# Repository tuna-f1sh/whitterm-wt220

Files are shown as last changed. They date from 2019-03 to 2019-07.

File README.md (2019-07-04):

```bash
        __        _______    ____  ____   ___
        \ \      / /_   _|  |___ \|___ \ / _ \
         \ \ /\ / /  | |_____ __) | __) | | | |
          \ V  V /   | |_____/ __/ / __/| |_| |
           \_/\_/    |_|    |_____|_____|\___/
       --- JBR Engineering Research Ltd 2019 ---
```

Design files, firmware and linux scripts for my _clever_ serial terminal, the
Whitterm-220 - WT-220. 

The WT-220 is a homage to the VT-220, providing a physical RS232 terminal with
the full features of a Linux computer running on a Raspberry Pi.

## Raspberry Pi Hat (./whitterm-hat)

KiCad design files for the rear io-panel:

* USB-C input for USB-PD high current (3 A) supply to RPi. LEDs indicate
  detected current profile from UFP. I2C lines made available to SAMD for
  playing with USB-C device modes.
* MAX3232 RS232 transceiver provides RS232 level interface to RPi UART and SAMD
  UART.
* SAMD21 microcontroller provides boot button control of RPi over I2C and
  buffered IO. Can be programmed over USB-C CDC-serial device or ISP.
* Control of RPi power supply from SAMD. Off by default allows safe start up, only when power input suitable/ready.
* DIP switch control of device UART connections (SAMD, RPi, RS232).
* Board replaces laser cut acrylic back piece from original design - it is
  both electronically and mechanically integrated.
* Lots of status LEDs 😃.

**There where a few green wires required for the first production (1.0). I
rolled these changes into the schematic but not fully updated the PCB.**

## Firmware (./firmware)

Arduino compatible firmware for rear panel SAMD21. Acts as I2C slave and
controls supply to RPi via 'Boot' button:

### Simplified State Diagram

```mermaid
graph TB;
    OFF-->|boot pressed 500 ms|ON;
    ON-->|I2C booted cmd recieved|BOOTED;
    ON-->|I2C recieve booted timeout 20000 ms|I2C_TIMEOUT;
    BOOTED-->|I2C recieve booted timeout 20000 ms|I2C_TIMEOUT;
    BOOTED-->|boot pressed 3000 ms|SHUTDOWN_REQUESTED;
    I2C_TIMEOUT-->|boot pressed 3000 ms|SHUTDOWN;
    I2C_TIMEOUT-->|I2C booted cmd recieved|BOOTED;
    SHUTDOWN_REQUESTED-->|I2C shutdown cmd|SHUTDOWN;
    SHUTDOWN_REQUESTED-->|boot pressed|ON;
    SHUTDOWN-->OFF;
```

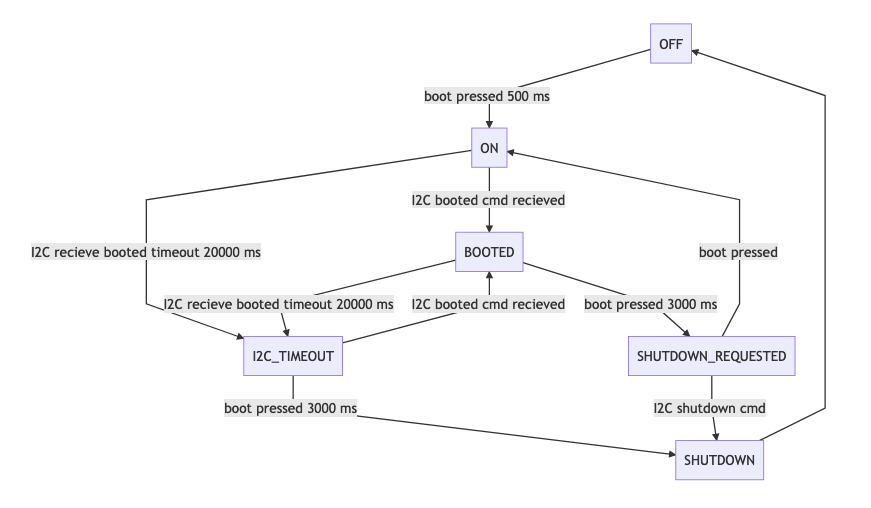
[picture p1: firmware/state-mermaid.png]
mermaid state


## RPi Files (./rpi)

I started from a base Raspbian Lite image rather than Arch for this build.
Raspbian Lite is nice because I could install only what I wanted/needed. I
opted for I3WM since it's a keyboard terminal.

### Services

* boot: Runs shell script that displays boot ascii logo.
* i2c: Runs python I2C script (wt220-i2c.py) that configures case LEDs to act
  on RX/TX and then maintains link with I2C link with SAMD. Polls shutdown
  request state and acts on request by issuing system shutdown.
* poweroff: Runs on 'shutdown.target' and issues the final I2C shutdown
  command so that SAMD disables RPi 5 V.

### Config Files

Would make an install script for this if I was making more...

* xinitrc -> /etc/X11/xinit/xinitrc
* config.txt, cmdline.txt -> /boot/
* Xresources -> ~/.Xresources
* motd -> /etc/motd
* wt220-sshbanner.net -> /etc/wt220-sshbanner.net `Banner /etc/wt220-sshbanner.net` in
  /etc/ssh/sshd_config
* \*services. -> /lib/systemd/system/
* scripts -> /opt/wt220/

### Packages

Need to manually install
[`cool-retro-term`](https://github.com/Swordfish90/cool-retro-term)

Other packages in 'rpi/dpkg-selections.txt'

## Breakout (./whitterm-breakout)

DB9 GPIO breakout from V 1.0 rear panel

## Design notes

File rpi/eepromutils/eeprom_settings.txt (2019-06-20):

########################################################################
# EEPROM settings text file
#
# Edit this file for your particular board and run through eepmake tool,
# then use eepflash tool to write to attached HAT ID EEPROM 
#
# Tools available:
#  eepmake   Parses EEPROM text file and creates binary .eep file
#  eepdump   Dumps a binary .eep file as human readable text (for debug)
#  eepflash  Write or read .eep binary image to/from HAT EEPROM
#
########################################################################

########################################################################
# Vendor info

# 128 bit UUID. If left at zero eepmake tool will auto-generate
# RFC 4122 compliant UUID
product_uuid 00000000-0000-0000-0000-000000000000

# 16 bit product id
product_id 0x0001

# 16 bit product version
product_ver 0x0001

# ASCII vendor string  (max 255 characters)
vendor "JBR Engineering Research Ltd"

# ASCII product string (max 255 characters)
product "WT-220 Rear IO-Panel"

########################################################################
# GPIO bank settings, set to nonzero to change from the default.
# NOTE these setting can only be set per BANK, uncommenting any of
# these will force the bank to use the custom setting.

# drive strength, 0=default, 1-8=2,4,6,8,10,12,14,16mA, 9-15=reserved
gpio_drive 0

# 0=default, 1=slew rate limiting, 2=no slew limiting, 3=reserved
gpio_slew 0

# 0=default, 1=hysteresis disabled, 2=hysteresis enabled, 3=reserved
gpio_hysteresis 0

# If board back-powers Pi via 5V GPIO header pins:
# 0 = board does not back-power
# 1 = board back-powers and can supply the Pi with a minimum of 1.3A
# 2 = board back-powers and can supply the Pi with a minimum of 2A
# 3 = reserved
# If back_power=2 then USB high current mode will be automatically 
# enabled on the Pi
back_power 2

########################################################################
# GPIO pins, uncomment for GPIOs used on board
# Options for FUNCTION: INPUT, OUTPUT, ALT0-ALT5
# Options for PULL: DEFAULT, UP, DOWN, NONE
# NB GPIO0 and GPIO1 are reserved for ID EEPROM so cannot be set

#         GPIO  FUNCTION  PULL
#         ----  --------  ----
#setgpio  2     INPUT     DEFAULT
#setgpio  3     INPUT     DEFAULT
#setgpio  4     INPUT     DEFAULT
#setgpio  5     INPUT     DEFAULT
#setgpio  6     INPUT     DEFAULT
#setgpio  7     INPUT     DEFAULT
#setgpio  8     INPUT     DEFAULT
#setgpio  9     INPUT     DEFAULT
#setgpio  10    INPUT     DEFAULT
#setgpio  11    INPUT     DEFAULT
#setgpio  12    INPUT     DEFAULT
#setgpio  13    INPUT     DEFAULT
#setgpio  14    INPUT     DEFAULT
#setgpio  15    INPUT     DEFAULT
#setgpio  16    INPUT     DEFAULT
#setgpio  17    INPUT     DEFAULT
#setgpio  18    INPUT     DEFAULT
#setgpio  19    INPUT     DEFAULT
#setgpio  20    INPUT     DEFAULT
#setgpio  21    INPUT     DEFAULT
#setgpio  22    INPUT     DEFAULT
#setgpio  23    INPUT     DEFAULT
#setgpio  24    INPUT     DEFAULT
#setgpio  25    INPUT     DEFAULT
#setgpio  26    INPUT     DEFAULT
#setgpio  27    OUTPUT    DEFAULT

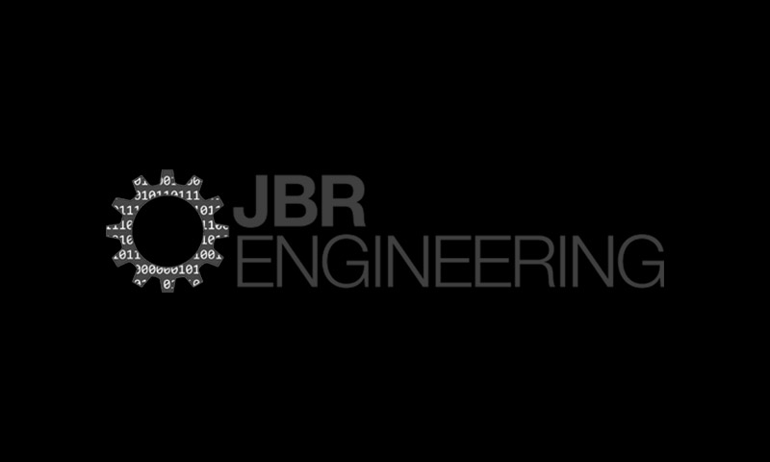
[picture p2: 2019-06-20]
rpi/wt220-background.jpg

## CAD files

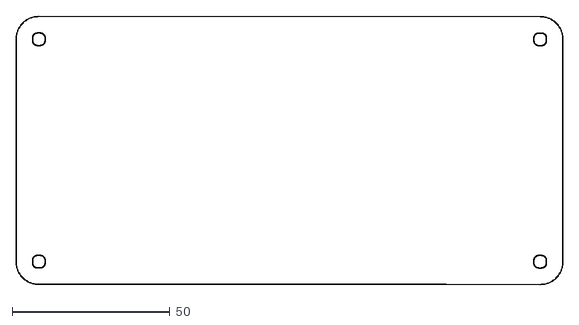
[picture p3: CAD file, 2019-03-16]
whitterm-hat/whitterm-rear-pcb.dxf
173.5 x 85.0

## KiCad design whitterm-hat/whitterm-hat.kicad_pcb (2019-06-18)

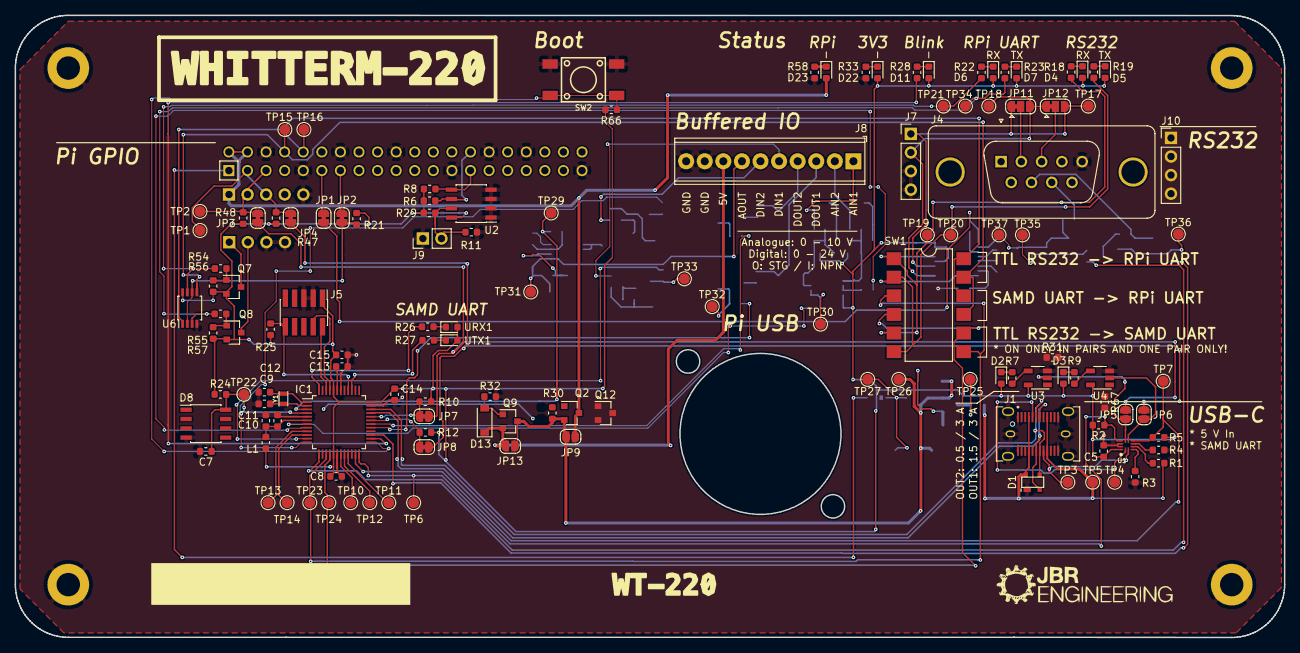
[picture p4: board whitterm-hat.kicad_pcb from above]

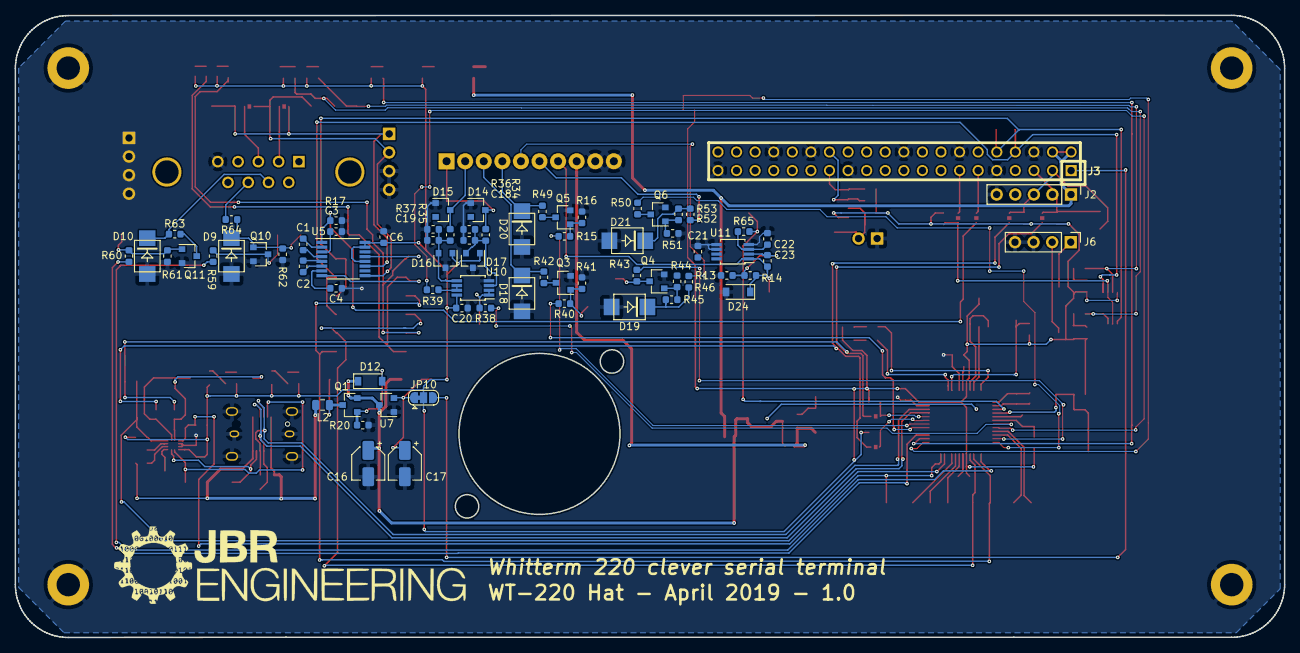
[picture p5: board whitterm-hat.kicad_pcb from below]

Board: 2 copper layers, 173.5 x 85.0 mm, 202 parts (72 on the bottom side), 127 nets.

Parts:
C1: 47nF; C_0603_1608Metric
C2, C3, C4: 330nF; C_0603_1608Metric
C5, C6, C18, C19, C20, C21: 100nF; C_0603_1608Metric
C7: 1uF; C_0603_1608Metric
C8, C10, C13, C14, C15: 0.1uF; C_0603_1608Metric
C9, C12: 15pF; C_0603_1608Metric
C11: 0.01uF; C_0603_1608Metric
C16, C17: 10uF; CP_Elec_4x5.3
C22: 470pF; C_0603_1608Metric
C23: 10pF; C_0603_1608Metric
D1: PRTR5V0U2X; SOT143B
D2: OUT2; LED_0603_1608Metric
D3: OUT1; LED_0603_1608Metric
D4: TLRX; LED_0603_1608Metric
D5: TLTX; LED_0603_1608Metric
D6: RXD; LED_0603_1608Metric
D7: TXD; LED_0603_1608Metric
D8: LM285D-2.5G; SOIC-8_3.9x4.9mm_P1.27mm
D9, D10, D18, D19, D20, D21: SMAJ30A-TR; D_DO-214AA
D11: D13; LED_0603_1608Metric
D12, D13: MMSZ16T1G; D_SOD-123
D14, D15: BZX84C10LT1G; D_SOT-23_ANK
D16, D17: BAV99; SOT-23
D22, D23: KP-2012MGC; LED_0603_1608Metric
D24: SMAJ12A-TR; D_SOD-123
IC1: SAMD21G18A; TQFP-48_7x7mm_P0.5mm
J1: USB_C_Receptacle; USB_C_Receptacle_JAE_DX07S024WJ1R350
J2: Touch I2C; PinHeader_1x05_P2.54mm_Vertical
J3: 40HAT; HEADER-2x20-REVERSE
J4: DB9_Male; DSUB-9_Male_Vertical_P2.77x2.84mm_MountingHoles
J5: Conn_02x05_Odd_Even; PinHeader_2x05_P1.27mm_Vertical_SMD
J6, J7, J10: Conn_01x04_Female; PinHeader_1x04_P2.54mm_Vertical
J8: Conn_01x10_Female; TerminalBlock_Phoenix_MPT-0,5-10-2.54_1x10_P2.54mm_Horizont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
J9: CONN_01X02; PinHeader_1x02_P2.54mm_Vertical
JP1, JP2, JP3, JP4, JP7, JP8: Jumper_2_Bridged; SolderJumper-2_P1.3mm_Bridged_RoundedPad1.0x1.5mm
JP5, JP6, JP9, JP13: Jumper_NO_Small; SolderJumper-2_P1.3mm_Open_RoundedPad1.0x1.5mm
JP10, JP11, JP12: SolderJumper_3_Bridged12; SolderJumper-3_P1.3mm_Bridged12_RoundedPad1.0x1.5mm
L1: LM18P; L_0603_1608Metric
L2: Ferrite_Bead_Small; L_0805_2012Metric
Q1, Q2, Q7, Q8, Q9: IRLML6402PBF; SOT-23
Q3, Q4, Q5, Q6, Q10, Q11, Q12: BC850; SOT-23
R1: 900k; R_0603_1608Metric
R2, R5, R17, R20, R21, R24, R25, R30, R31, R32, R56, R57, R66, R67: 10k; R_0603_1608Metric
R3, R4: 0R; R_0603_1608Metric
R6, R8, R10, R12, R47, R48: 4.7K; R_0603_1608Metric
R7, R9, R18, R19, R22, R23, R26, R27, R28, R33: 150R; R_0603_1608Metric
R11: DNP; R_0603_1608Metric
R13, R14: 100k; R_0603_1608Metric
R15, R40, R42, R43, R45, R46, R49, R50, R52, R53, R54, R55, R59, R60, R63, R64: 470R; R_0603_1608Metric
R16, R38, R39, R41, R44, R51, R61, R62, R65: 1k; R_0603_1608Metric
R29: 10K; R_0603_1608Metric
R34, R35: 9k1; R_0603_1608Metric
R36, R37: 3k9; R_0603_1608Metric
R58: 220R; R_0603_1608Metric
SW1: SW_DIP_x06; SMDIP-12_W9.53mm
SW2: SW_Push; SPST-4-PIN_6mm_sm
TP1, TP2, TP3, TP4, TP5, TP6, TP7, TP10, TP11, TP12, TP13, TP14, TP15, TP16, TP17, TP18, TP19, TP20, TP21, TP22, TP23, TP24, TP25, TP26, TP27, TP29, TP30, TP31, TP32, TP33, TP34, TP35, TP36, TP37: TestPoint; TestPoint_Pad_D1.5mm
U1: TUSB320; TI_RWB_X2QFN-12
U2: CAT24C32WI-GT3; SOIC-8_3.9x4.9mm_P1.27mm
U3, U4: 74LVC1G17; TSOT-23-5
U5: MAX3221; TSSOP-16_4.4x5mm_P0.65mm
U6: 74LVC2G02; TSSOP-8_3x3mm_P0.65mm
U7: MCP1703A-3302_SOT23; SOT-23
U10, U11: ADA4807-2ARM; MSOP-8_3x3mm_P0.65mm
URX1: RXD; LED_0603_1608Metric
UTX1: TXD; LED_0603_1608Metric
Y1: 32.768; Crystal_2-SMD_2x1.2mm
svg2mod: G***; whitterm220-fullname
svg2mod#2: G***; whitterm220-wt220

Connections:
+5V: C16.1, C21.2, D12.1, JP9.1, JP13.1, Q1.2, Q2.2, Q9.3, R30.1, TP26.1, U7.3, U11.8
/D+: D1.3, IC1.34, J1.A6, J1.B6
/D-: D1.2, IC1.33, J1.A7, J1.B7
/EXT_5VO: D13.1, J8.8, JP13.2, Q9.2
/ID_SC_EEPROM: J3.28, R6.1, U2.6
/ID_SD_EEPROM: J3.27, R8.1, U2.5
/PI_3V3: J3.1, JP10.3
/PI_5V: D23.2, J2.1, J3.2, J3.4, JP9.2, Q2.3
/PI_EN: IC1.14, Q12.1
/PI_RXD: J3.10, J10.1, SW1.10, SW1.12, TP16.1, U6.1
/PI_SCL: J2.2, J3.5, JP3.1, R48.1, TP2.1
/PI_SDA: J2.3, J3.3, JP4.1, R47.1, TP1.1
/PI_TXD: J3.8, J10.2, SW1.9, SW1.11, TP15.1, U6.5
/RS232-UART/RS232_CTS: J4.8, R64.2
/RS232-UART/RS232_RTS: D10.1, J4.7, R63.1
/RS232-UART/RS232_RX: J7.1, JP11.1, JP12.3, TP17.1, U5.11
/RS232-UART/RS232_TX: J7.2, JP11.3, JP12.1, TP18.1, U5.9
/RS232-UART/RXD_LEDC: J6.1, Q7.3
/RS232-UART/TTL_RX: R18.1, SW1.1, SW1.5, TP19.1, U5.13
/RS232-UART/TTL_TX: R19.1, SW1.2, SW1.6, TP20.1, U5.8
/RS232-UART/TXD_LEDC: J6.2, Q8.3
/SAMD_RXD: IC1.16, J10.3, SW1.4, SW1.8, TP24.1
/SAMD_TXD: IC1.15, J10.4, SW1.3, SW1.7, TP23.1
/USBC_ID: IC1.24, R2.1, TP6.1, U1.9
/USBC_INT: IC1.23, R5.1, TP7.1, U1.6
/USBC_SCL: JP3.2, JP5.2, JP7.1
/USBC_SDA: JP4.2, JP6.2, JP8.1
/U_CTS: IC1.13, R59.1
/U_RTS: IC1.27, R60.2
/buffers/AIN_I1: D14.1, J8.1, R34.2
/buffers/AIN_I2: D15.1, J8.2, R35.2
/buffers/AOUT_O1: C23.1, D24.1, J8.7, R14.1, TP31.1, U11.1
/buffers/DIN_I1: J8.5, R46.2
/buffers/DIN_I2: J8.6, R53.2
/buffers/DOUT_O1: D18.1, J8.3, R42.1
/buffers/DOUT_O2: D20.1, J8.4, R49.1
/microcontroller/A0_DAC: IC1.3, R65.2, TP29.1
/microcontroller/A1: IC1.7, R38.1
/microcontroller/A2: IC1.8, R39.1
/microcontroller/A3: IC1.9, TP13.1
/microcontroller/A4: IC1.10, TP14.1
/microcontroller/D6: IC1.29, R40.2
/microcontroller/D7: IC1.30, R15.2
/microcontroller/D8: IC1.11, R43.1
/microcontroller/D9: IC1.12, R50.1
/microcontroller/D11: IC1.25, R66.2, SW2.2
/microcontroller/D13: IC1.26, R28.1
/microcontroller/MISO: IC1.21, TP11.1
/microcontroller/MOSI: IC1.19, TP10.1
/microcontroller/NRST: IC1.40, J5.10, R25.2
/microcontroller/RX_LED: IC1.48, R26.1
/microcontroller/SCK: IC1.20, TP12.1
/microcontroller/SCL: IC1.32, JP7.2, R10.1
/microcontroller/SDA: IC1.31, JP8.2, R12.1
/microcontroller/SWDCLK: IC1.45, J5.4
/microcontroller/SWDIO: IC1.46, J5.2
/microcontroller/TX_LED: IC1.39, R27.1
/~RPI_EN_ACT: JP2.1, R21.1, U6.2, U6.6
/~RS232_EN: JP1.1, R17.2, U5.1
GND: C3.1, C4.1, C5.1, C6.1, C7.2, C8.2, C9.2, C10.2, C11.2, C12.2, C13.2, C14.2, C15.2, C16.2, C17.2, C18.2, C19.2, C20.1, C21.1, C22.2, D1.1, D8.4, D9.2, D10.2, D14.2, D15.2, D16.3, D17.3, D18.2, D19.2, D20.2, D21.2, D24.2, IC1.5, IC1.18, IC1.35, IC1.42, J1.A1, J1.A12, J1.B1, J1.B12, J1.S1, J2.5, J3.6, J3.9, J3.14, J3.20, J3.25, J3.30, J3.34, J3.39, J4.5, J5.3, J5.5, J6.3, J6.4, J7.3, J7.4, J8.9, J8.10, J9.1, Q3.2, Q4.2, Q5.2, Q6.2, Q10.2, Q11.2, Q12.2, R3.1, R4.1, R11.2, R13.1, R16.1, R17.1, R20.2, R32.2, R33.2, R36.1, R37.1, R41.1, R44.1, R51.1, R58.2, R61.1, R62.1, SW2.1, U1.10, U1.11, U2.1, U2.2, U2.3, U2.4, U3.3, U4.3, U5.14, U6.4, U7.1, U10.4, U11.4, U11.5, U11.6
unnamed: C1.1, U5.2
unnamed: C1.2, U5.4
unnamed: C2.1, U5.5
unnamed: C2.2, U5.6
unnamed: C3.2, U5.3
unnamed: C4.2, U5.7
unnamed: C7.1, D8.8, IC1.4, R24.2, TP22.1
unnamed: C9.1, IC1.2, Y1.1
unnamed: C10.1, C11.1, IC1.6, L1.1
unnamed: C12.1, IC1.1, Y1.2
unnamed: C13.1, IC1.43
unnamed: C17.1, JP10.1, TP27.1, U7.2
unnamed: C18.1, D17.2, R34.1, R36.2, U10.3
unnamed: C19.1, D16.2, R35.1, R37.2, U10.5
unnamed: C22.1, R65.1, U11.3
unnamed: C23.2, R13.2, R14.2, U11.2
unnamed: D2.1, R7.2
unnamed: D3.1, R9.2
unnamed: D4.1, R18.2
unnamed: D5.1, R19.2
unnamed: D6.1, R22.2
unnamed: D7.1, R23.1
unnamed: D9.1, Q10.1, R62.2, R64.1, TP37.1
unnamed: D11.1, R28.2
unnamed: D12.2, Q1.1, R20.1
unnamed: D13.2, Q9.1, R32.1
unnamed: D19.1, R45.2, R46.1
unnamed: D21.1, R52.2, R53.1
unnamed: D22.1, R33.1
unnamed: D23.1, R58.1
unnamed: J1.A5, TP4.1, U1.1
unnamed: J1.B5, TP3.1, U1.2
unnamed: J3.11, JP1.2
unnamed: J3.13, JP2.2
unnamed: J4.2, JP11.2
unnamed: J4.3, JP12.2
unnamed: J9.2, R11.1, R29.1, U2.7
unnamed: JP5.1, R31.1, U1.8, U3.2
unnamed: JP6.1, R67.1, U1.7, U4.2
unnamed: L2.1, Q1.3, TP25.1
unnamed: Q3.1, R40.1, R41.2, TP32.1
unnamed: Q3.3, R42.2
unnamed: Q4.1, R44.2, R45.1
unnamed: Q4.3, R43.2, TP33.1
unnamed: Q5.1, R15.1, R16.2
unnamed: Q5.3, R49.2
unnamed: Q6.1, R51.2, R52.1
unnamed: Q6.3, R50.2
unnamed: Q7.1, R54.2, R56.1
unnamed: Q8.1, R55.2, R57.1
unnamed: Q10.3, R59.2, TP35.1
unnamed: Q11.1, R60.1, R61.2, TP36.1
unnamed: Q11.3, R63.2
unnamed: Q2.1, Q12.3, R30.2
unnamed: R1.1, U1.4
unnamed: R3.2, U1.3
unnamed: R4.2, U1.5
unnamed: R7.1, U3.4
unnamed: R9.1, U4.4
unnamed: R22.1, R54.1, TP21.1, U6.7
unnamed: R23.2, R55.1, TP34.1, U6.3
unnamed: R26.2, URX1.1
unnamed: R27.2, UTX1.1
unnamed: R38.2, TP30.1, U10.1, U10.2
unnamed: R39.2, U10.6, U10.7
VBUS: D1.4, J1.A4, J1.A9, J1.B4, J1.B9, L2.2, R1.2, TP5.1
VCC: C5.2, C6.2, C8.1, C14.1, C15.1, C20.2, D2.2, D3.2, D4.2, D5.2, D6.2, D7.2, D11.2, D16.1, D17.1, D22.2, IC1.17, IC1.36, IC1.44, J5.1, JP10.2, L1.2, Q7.2, Q8.2, R2.2, R5.2, R6.2, R8.2, R10.2, R12.2, R21.2, R24.1, R25.1, R29.2, R31.2, R47.2, R48.2, R56.2, R57.2, R66.1, R67.2, U1.12, U2.8, U3.5, U4.5, U5.12, U5.15, U5.16, U6.8, U10.8, URX1.2, UTX1.2

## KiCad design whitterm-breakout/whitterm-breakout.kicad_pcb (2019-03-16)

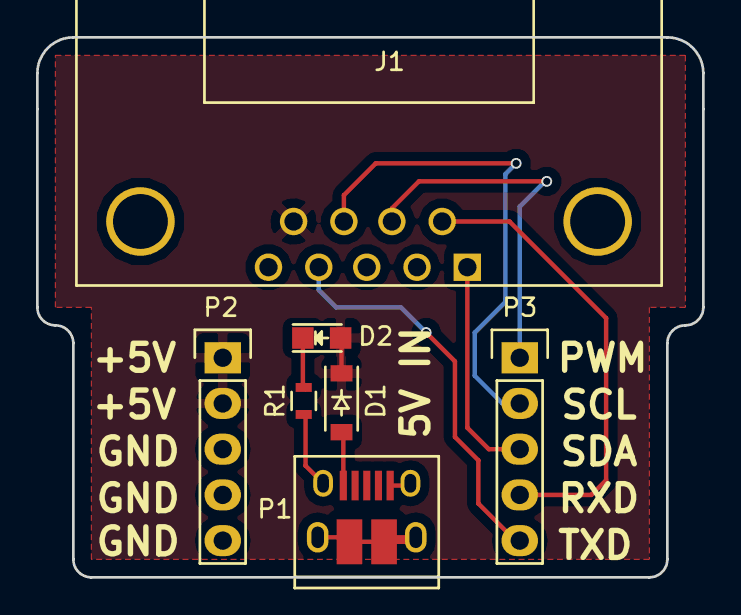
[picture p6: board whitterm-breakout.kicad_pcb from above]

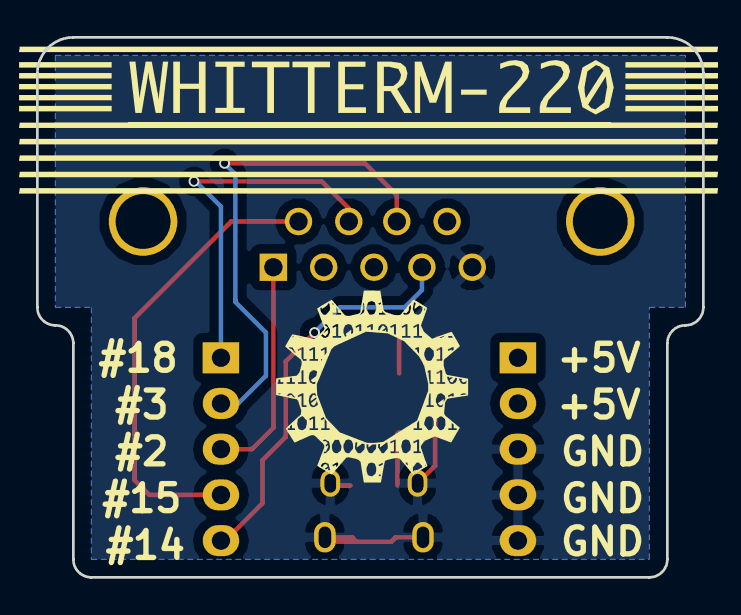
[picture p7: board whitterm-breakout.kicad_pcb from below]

Board: 2 copper layers, 37.0 x 30.0 mm, 9 parts (2 on the bottom side), 9 nets.

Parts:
D1: MBR0520L; SOD-123
D2: LED; LED_0805
J1: DB9; DB9MC
P1: USB_OTG; USB_Micro-B_10103594-0001LF
P2, P3: CONN_01X05; Pin_Header_Straight_1x05
R1: R330; R_0603
jbrbinary: G***; jbrbinary
whitterm220-logo: G***; whitterm220

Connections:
#2_SDA: J1.1, P3.3
#3_SCL: J1.8, P3.2
#14_TXD: J1.4, P3.5
#15_RXD: J1.6, P3.4
#18_PWM: J1.7, P3.1
GND: J1.5, P1.5, P1.6, P2.3, P2.4, P2.5, R1.2
unnamed: D1.2, P1.1
unnamed: D2.1, R1.1
VCC: D1.1, D2.2, J1.9, P2.1, P2.2

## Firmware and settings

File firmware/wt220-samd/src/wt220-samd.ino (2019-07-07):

/*
 * Copyright (c) 2019 John Whittington.
 *
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
 * You should have received a copy of the GNU General Public License
 * along with this program. If not, see <http://www.gnu.org/licenses/>.
 */

#include "wt220-samd.h"
#include "i2c.h"

#include <RBD_Timer.h>
#include <RBD_Button.h>

// TODO - add serial or I2C read-back of external I/O

RBD::Button boot(BOOT_BTN_PIN); // input_pullup by default
RBD::Timer pressTimer(BOOT_HOLD_DELAY);
state_t state = state_t::PI_OFF;

RBD::Timer ledTask(10);
struct led_t {
  uint16_t counter = 0;
  uint16_t current_count = 0;
} main_led;

RBD::Timer outTestTask(50);
RBD::Timer shutdownTimer(3000);
RBD::Timer i2cTimeoutTimer(20000);

Uart *ExtSerial = &Serial1;
#if DEBUG_DEVICE == 0
  Uart *DbgSerial = SerialUSB;
#elif DEBUG_DEVICE == 1
  Uart *DbgSerial = ExtSerial;
#endif

const char* serialStart = "\
-------------- WT 220 SAMD --------------\n\
------- IO Panel Microcontroller --------\n\
--- JBR Engineering Research Ltd 2019 ---\n";

static inline void setup_rs232() {
  pinMode(RS232_RTS_PIN, OUTPUT); digitalWrite(RS232_RTS_PIN, LOW);
  pinMode(RS232_CTS_PIN, INPUT);
  ExtSerial->begin(9600); // ttl to rs232
}

static inline void setup_gpio() {
  pinMode(LED_PIN, OUTPUT);

  pinMode(NOT_PI_EN_PIN, OUTPUT); digitalWrite(NOT_PI_EN_PIN, HIGH);

  pinMode(USBC_INT_PIN, INPUT); pinMode(USBC_ID_PIN, INPUT);

  // buffered inputs/outputs
  analogWriteResolution(ALOG_RESOLUTION_BITS);
  analogReadResolution(ALOG_RESOLUTION_BITS);
  /* analogReference(AR_EXTERNAL); */

  pinMode(AIN1_PIN, INPUT); pinMode(AIN2_PIN, INPUT);
  pinMode(DIN1_PIN, INPUT_PULLUP); pinMode(DIN2_PIN, INPUT_PULLUP);

  pinMode(DOUT1_PIN, OUTPUT); pinMode(DOUT2_PIN, OUTPUT);
  digitalWrite(DOUT1_PIN, HIGH); digitalWrite(DOUT2_PIN, HIGH);
}

static void set_aout_voltage(float voltage) {
  uint16_t data = 0;

  if (voltage > AOUT_MAX_VOLTAGE) {
    voltage = AOUT_MAX_VOLTAGE;
  }

  voltage /= AOUT_GAIN;
  voltage /= EXT_ALOG_REF;
  voltage *= MAX_DAC_VALUE;

  data = (uint16_t) voltage;

  analogWrite(AOUT1_PIN, data);
}

static float read_ain_voltage(uint16_t pin) {
  float voltage = 0.0;

  voltage = (float) analogRead(pin) / MAX_ALOG_VALUE;
  voltage *= EXT_ALOG_REF;
  voltage *= AIN_GAIN;

  return voltage;
}

void startShutdown(uint16_t timeout = 3000) {
  setState(state_t::SHUTTING_DOWN);
  shutdownTimer.setTimeout(timeout);
  shutdownTimer.restart();
}

state_t getState(void) {
  return state;
}

void setState(state_t new_state) {
  SerialUSB.print("SYS: "); SerialUSB.print((int) state); SerialUSB.print(" to "); SerialUSB.println((int) new_state);
  state = new_state;

  switch (state) {
    case state_t::PI_ON:
      SerialUSB.println("SYS: Enabling 5 V RPi line");
      digitalWrite(NOT_PI_EN_PIN, LOW);
      // start the i2c timer timeout
      i2cTimeoutTimer.restart();
      break;
    case state_t::PI_OFF:
      SerialUSB.println("SYS: Disabling 5 V RPi line");
      digitalWrite(NOT_PI_EN_PIN, HIGH);
      i2cTimeoutTimer.stop();
      break;
    case state_t::SHUTDOWN_REQUEST:
      SerialUSB.println("SYS: Request shutdown");
    default:
      break;
  }
}

void setup() {
  setup_gpio();
  setup_rs232();
  setup_i2c_slave();

  // hold in setup while boot pressed at boot
  while(boot.isPressed()) {
    for (int i = MAX_ALOG_VALUE; i > 0; i--) {
      analogWrite(LED_PIN, i);
      delayMicroseconds(100);
    }
  }

  pressTimer.stop();
  shutdownTimer.stop();
  i2cTimeoutTimer.stop();

  if (!PRINT_AIN) {
    outTestTask.stop();
  }

  SerialUSB.print(serialStart);
  SerialUSB.print("SYS V: "); SerialUSB.print(VERSION_MAJOR); SerialUSB.print("."); SerialUSB.print(VERSION_MINOR);
}

void loop() {
  static float aout = 0.0;

  if (ledTask.onRestart()) {
    ++main_led.counter;
    switch (state) {
      case state_t::PI_OFF:
        if (!(main_led.counter % 100))
          // on
          main_led.current_count = MAX_ALOG_VALUE >> 1;
        else if (!(main_led.counter % 10))
          // off
          main_led.current_count = MAX_ALOG_VALUE;
        break;
      case state_t::PI_ON:
        // fade up quickly
        if (main_led.current_count - 20 > 0) 
          main_led.current_count -= 20;
        else
          main_led.current_count = MAX_DAC_VALUE;
        break;
      default:
      case state_t::PI_BOOTED:
        // steady on
        main_led.current_count = MAX_ALOG_VALUE >> 1;
        break;
      case state_t::I2C_TIMEOUT:
        // steady dimmer
        main_led.current_count = (MAX_ALOG_VALUE >> 1) + 1024;
        break;
      case state_t::SHUTTING_DOWN:
        // fade down quickly
        if (main_led.current_count < MAX_ALOG_VALUE) 
          main_led.current_count += 20;
        else
          main_led.current_count = (MAX_DAC_VALUE >> 1);
        break;
      case state_t::SHUTDOWN_REQUEST:
        if (!(main_led.counter % 20))
          // on
          main_led.current_count = MAX_ALOG_VALUE >> 1;
        else if (!(main_led.counter % 10))
          // off
          main_led.current_count = MAX_ALOG_VALUE;
        break;
    }
    analogWrite(LED_PIN, main_led.current_count);
  }

  if (outTestTask.onRestart()) {
    set_aout_voltage(aout);
    if (aout < 3.3) {
      aout += 0.1;
    } else {
      aout = 0.0;
    }

    if (PRINT_GRAPH) {
      DbgSerial->println(read_ain_voltage(AIN1_PIN));
    } else {
      SerialUSB.print("AIN Count: "); SerialUSB.print(analogRead(AIN1_PIN));
      SerialUSB.print(" Voltage / V: "); SerialUSB.println(read_ain_voltage(AIN1_PIN));
    }
  }

  if (i2cTimeoutTimer.onRestart()) {
    setState(state_t::I2C_TIMEOUT);
  }

  if (boot.onPressed()) {
    // if 5 V RPI supply is not enabled, set enable hold delay
    if (state == state_t::PI_OFF) {
      pressTimer.setTimeout(BOOT_HOLD_DELAY);
    // allow cancel request if not acted on
    } else if (state == state_t::SHUTDOWN_REQUEST) {
      SerialUSB.println("SYS: Abort shutdown");
      setState(state_t::PI_ON);
    // otherwise, set shutdown delay
    } else if (state != state_t::SHUTTING_DOWN) {
      pressTimer.setTimeout(SHUTDOWN_HOLD_DELAY);
    }

    pressTimer.restart();
  } else if (boot.isPressed()) {
    if (pressTimer.onExpired()) {
      if (state == state_t::PI_OFF) {
        setState(state_t::PI_ON);
      } else {
        // first issue shutdown request
        if (state == state_t::PI_ON || state == state_t::PI_BOOTED) {
          setState(state_t::SHUTDOWN_REQUEST);
        // but if held again or in timeout, force shutdown
        } else {
          startShutdown();
        }
      }
    }
  } else if (boot.onReleased()) {
    pressTimer.stop();
  }

  if (shutdownTimer.onRestart()) {
    setState(state_t::PI_OFF);
    shutdownTimer.stop();
  }

  if (ECHO_EXTSERIAL) {
    if (SerialUSB.available()) {      // If anything comes in Serial (USB),
      ExtSerial->write(SerialUSB.read());   // read it and send it out Serial1 (pins 0 & 1)
    }

    if (ExtSerial->available()) {     // If anything comes in Serial1 (pins 0 & 1)
      SerialUSB.write(ExtSerial->read());   // read it and send it out Serial (USB)
    }
  }
}

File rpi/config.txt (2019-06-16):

# For more options and information see
# http://rpf.io/configtxt
# Some settings may impact device functionality. See link above for details
lcd_rotate=2

# uncomment if you get no picture on HDMI for a default "safe" mode
#hdmi_safe=1

# uncomment this if your display has a black border of unused pixels visible
# and your display can output without overscan
#disable_overscan=1

# uncomment the following to adjust overscan. Use positive numbers if console
# goes off screen, and negative if there is too much border
#overscan_left=16
#overscan_right=16
#overscan_top=16
#overscan_bottom=16

# uncomment to force a console size. By default it will be display's size minus
# overscan.
#framebuffer_width=1280
#framebuffer_height=720

# uncomment if hdmi display is not detected and composite is being output
#hdmi_force_hotplug=1

# uncomment to force a specific HDMI mode (this will force VGA)
#hdmi_group=1
#hdmi_mode=1

# uncomment to force a HDMI mode rather than DVI. This can make audio work in
# DMT (computer monitor) modes
#hdmi_drive=2

# uncomment to increase signal to HDMI, if you have interference, blanking, or
# no display
#config_hdmi_boost=4

# uncomment for composite PAL
#sdtv_mode=2

#uncomment to overclock the arm. 700 MHz is the default.
#arm_freq=800

# Uncomment some or all of these to enable the optional hardware interfaces
dtparam=i2c_arm=on
#dtparam=i2s=on
#dtparam=spi=on

# Uncomment this to enable the lirc-rpi module
#dtoverlay=lirc-rpi

# Additional overlays and parameters are documented /boot/overlays/README
avoid_warnings=2 additionally allows turbo when low-voltage is present.
disable_splash=1

# Enable audio (loads snd_bcm2835)
dtparam=audio=on

# Still allow BLE on miniuart
dtoverlay=pi3-miniUart-bt
core_freq=250

# GPU settings
gpu_mem=256

dtoverlay=vc4-fkms-v3d

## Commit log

2019-03-16 first commit, hat schematic captured
    [RS232-UART.sch, buffers.sch, config.txt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]
2019-04-05 pcb sent for production
    [RS232-UART.sch, buffers.sch, micro.sch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]
2019-05-31 firmware added and bring up R value changes
    [micro.sch, whitterm-hat.sch]
2019-06-05 button button logic
    [buffers.sch, whitterm-hat.kicad_pcb, whitterm-hat.sch]
2019-06-10 mods during bring up, see notes
    [RS232-UART.sch, buffers.sch, micro.sch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]
2019-06-10 bring up firmware, all hardware testing and changes rolled into schematic
    [buffers.sch, whitterm-hat.sch]
2019-06-14 stuff from rpi
    [config.txt]
2019-06-14 correct pin and logic for activity LED
2019-06-16 i2c monitor script and service
    [config.txt]
2019-06-16 firmware functionally complete for basic button usage
    [buffers.sch, power.sch, whitterm-hat.kicad_pcb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]
2019-06-18 fix power off service user
    [wt220-i2c.py]
2019-06-18 remove abort shutdown so that hard shutdown available
    [whitterm-hat.kicad_pcb]
2019-06-20 add i2c timeout state
2019-07-04 buffer on RS232 LEDs
    [RS232-UART.sch]
2019-09-25 add rescue lib for hat PCB

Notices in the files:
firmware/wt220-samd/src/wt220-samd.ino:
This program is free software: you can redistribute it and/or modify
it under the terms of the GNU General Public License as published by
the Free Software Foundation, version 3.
